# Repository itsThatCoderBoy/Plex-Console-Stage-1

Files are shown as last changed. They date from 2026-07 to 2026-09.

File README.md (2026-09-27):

# Plex Console Stage 1
## A small devboard that attaches to modules to give endless emulation possibilities!
The way it works is simple: Have the main board, attach it to whatever output device is needed for the game you want to play, and bam! You have a small pocket-sized devboard with endless possibilities of emulation. All you have to do is make your attachment board, code the game, and snap on the main board!\
**This is Stage 1 of this project; it is just the Devboard. After I build this project and it (hopefully) works, I am going to add a case and move on making a tester module.**\
This is my first project as part of Hack Club, and I certainly hope it isn't my last! This has already been so fun, even just a couple hours in.

## Why & How
This project came about because i really liked Bitluni's Megaplex video (oh boy I wonder where the name came from), and I wanted to make something inspired by it.\
I initially was thinking of doing something exactly like his, but then realised that that would be a bad idea, and so I decided to make it my own by adding:
 - Different battery (rechargable!)
 - Modular snap-on system
 - Completely different display (ok this is an entirely different thing)

Thank you so much to Hack Club and Forge for making this whole thing possible! This really is an amazing oppurtunity.

## What is it?
This project firstly involves a devboard. The reason it isn't a single board with the I/O and everything is because the main devboard is one of the more expensive things (~$35-40 including shipping for components), and I wanted you to just have one for all of the possible modules. (Also because I wanted a concrete starting point)\
**Note: This is a test for just the devboard. I am going to make a case and print it myself when I have confirmation that it works and I will be able to measure something concrete. Also, the 3D model on KiCad is missing quite a few componenets and I am going to need those in order to make a good case.**\
The second part of the project is the modules. They snap onto the devboard with magnets and communicate with pads on the back of both. Modules can do anything, as long as you code it right and have enough I/O pins!

## What's the Plan?
I currently have the devboard designed and ready to ship off to JLCPCB when I get funding!\
The first module that I am going to create is just a simple screen made of Charlie-Plexed LEDS. This is mainly just to practice coding, get the connection between the devboard and module hammered down, and make sure that the devboard works of course.\
After that, I move on to the main idea: The Nintendon't GameMan. This is basically a Gameboy-like little pocket console with famous games like Tesris, Pac-Boy, and maybe even Toader! I haven't gotten to this point yet of course, but I am moving swiftly along.
Last but not least, if I have any extra time, I'd eventually like to make other attachments (feel free to leave suggestions).

## Current Progress:

### *Devboard*
*Schematic*\
Schematic of Devboard

*PCB Layout*\
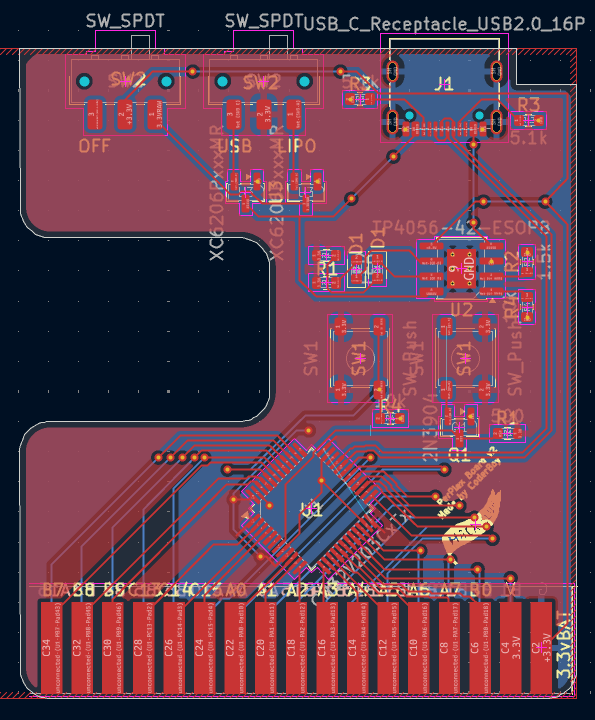
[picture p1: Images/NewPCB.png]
PCB Layout of Devboard


*Built-in KiCad 3D Model Front*\
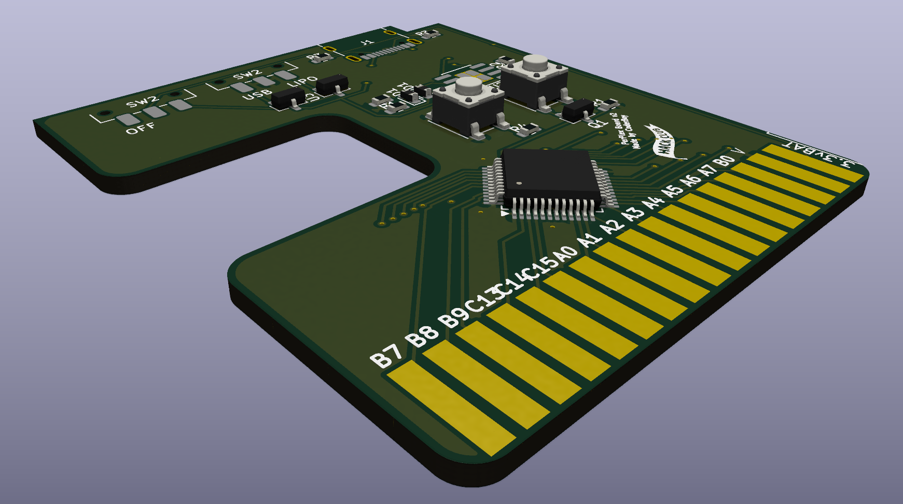
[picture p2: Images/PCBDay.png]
Built-in KiCad 3D Model Front of Devboard


*Build Photo*
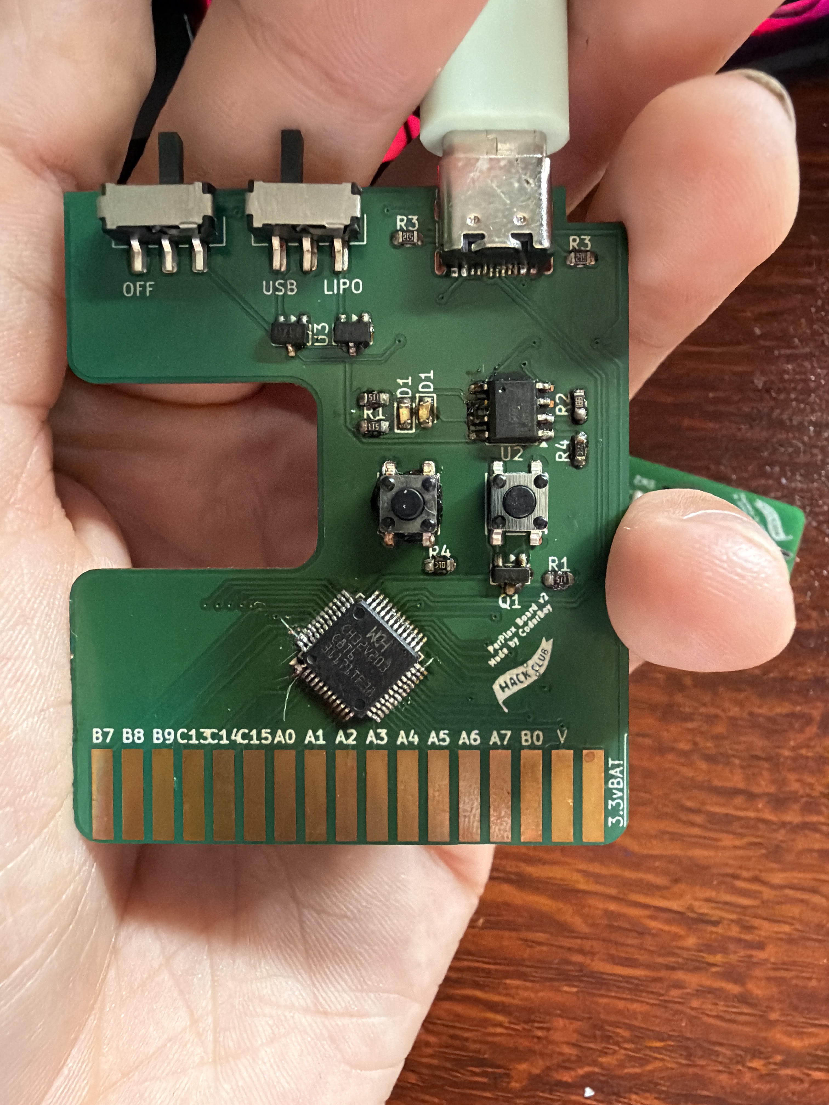
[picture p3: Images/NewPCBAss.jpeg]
Build Photo


## BOM

DevboardBOM

## Build

[View my project timeline on Lapse](https://lapse.hackclub.com/user/@itsthatcoderboy)

https://github.com/user-attachments/assets/fe2d55e1-1f7b-49ab-ab0b-663dc05e2e7f

https://github.com/user-attachments/assets/89aea018-e0ea-4a9d-9f60-57c4afef2afe

https://github.com/user-attachments/assets/4f556e5a-54bf-4c0b-9238-5e6fd982241c

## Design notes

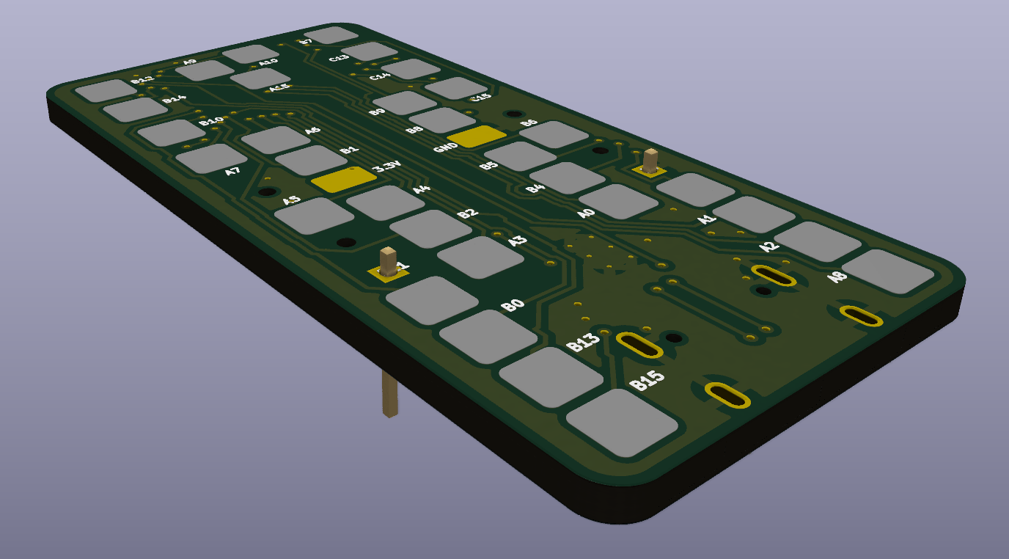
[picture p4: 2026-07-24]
Images/PCBBack.png

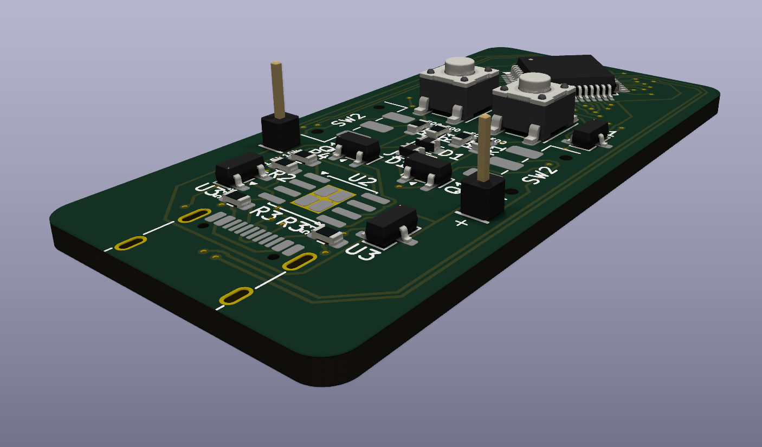
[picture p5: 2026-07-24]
Images/PCBFront.png

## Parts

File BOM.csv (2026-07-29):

Devboard BOM
Components: |  |  |  |  |  | Just For Me
Reference | Value | Qty | Footprint | Shop Link: | Shop Details: | Will I need to buy it? | Shipping? (^ = ships with) | Coupon?
D1 | LED (Any Color) | 2 | D_0603 (1608 Metric) | lcsc.com/product-detail/C19273151.html | LCSC - $ 0.59 for 100 | Y | $12.57 (includes Handling fee) | N
J1 | USB-C 2.0 16pin Jack | 1 | USB-C Receptacle G-Switch GT-USB-7010ASV | lcsc.com/product-detail/C5178539.html | LCSC - $ 0.36 for 5 | Y | ^ | N
Q1 | 2N3904 Transistor | 3 | SOT-23 | lcsc.com/product-detail/C18536.html | LCSC - $ 0.29 for 25 | N
R1 | 500Ω | 5 | R_0603 (1608 Metric) | lcsc.com/product-detail/C6207671.html | LCSC - $ 0.63 for 20 | N
R2 | 1.5kΩ | 1 | R_0603 (1608 Metric) | lcsc.com/product-detail/C2930050.html | LCSC - $ 0.29 for 100 | N
R3 | 5.1kΩ | 2 | R_0603 (1608 Metric) | lcsc.com/product-detail/C2907044.html | LCSC - $ 0.28 for 100 | N
R4 | 10kΩ | 2 | R_0603 (1608 Metric) | lcsc.com/product-detail/C2906982.html | LCSC - $ 0.42 for 100 | N
SW1 | Push-Button Switch | 2 | SW SPST PTS647 Sx38 | lcsc.com/product-detail/C36938886.html | LCSC - $ 1.01 for 50 | Y | ^ | N
SW2 | SPDT Slide Switch | 2 | SW SPDT CK JS102011SAQN | lcsc.com/product-detail/C49023767.html | LCSC - $ 0.39 for 5 | Y | ^ | N
U1 | CH32V203C8T6 | 1 | LQFP-48 7x7mm P0.5mm | lcsc.com/product-detail/C3001172.html | LCSC - $ 0.87 for 1 | Y | ^ | N
U2 | TP4056-42-ESOP8 | 1 | SOIC-8-1EP 3.9x4.9mm P1.27mm EP2.41x3.3mm ThermalVias | lcsc.com/product-detail/C16581.html | LCSC - $ 0.93 for 5 | Y | ^ | N
U3 | XC6206P302MR-G | 1 | SOT-23 | lcsc.com/product-detail/C9972.html | LCSC - $ 0.81 for 5 | Y | ^ | N
BATTERY | 802045 800 mAh | 1 | 8 mm x 20 mm x 45 mm | ebay.com/itm/254702348768 | Ebay - $ 7.22 for 1 | Y | $2.99 | N
Items:
PCB |  | 1 |  | jlcpcb.com | JLCPCB - $5.10 for 5 | Y | $3.22 | Y, -$ 5
Solder Paste |  | 1 |  | aliexpress.us/item/3256809162577166.html | AliExpress - $ 4.37 for 10g | Y | Free | Y, -$ 3.38
Total (For Me): | $ 17 @ LCSC, $ 10.21 @ Ebay, $ 1.07 @ AliExpress, $ 3.22 @ JLCPCB = $ 31.50*
Total Raw: | $ 19.37 @ LCSC, $ 10.21 @ Ebay, $ 4.37 @ AliExpress, $ 8.22 @ JLCPCB = $ 39.88*
 | * Note: There may be taxes, so add a little bit to cover that

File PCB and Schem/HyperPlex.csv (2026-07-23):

'Reference' | 'Value' | 'Footprint' | 'Qty'
'D1,D2' | 'LED' | 'Diode_SMD:D_0603_1608Metric' | '2'
'J1' | 'USB_C_Receptacle_USB2.0_16P' | 'Connector_USB:USB_C_Receptacle_G-Switch_GT-USB-7010ASV' | '1'
'Q1,Q2,Q3' | '2N3904' | 'Package_TO_SOT_SMD:SOT-23' | '3'
'R1,R14' | '10k' | 'Resistor_SMD:R_0603_1608Metric' | '2'
'R2' | '1.5k' | 'Resistor_SMD:R_0603_1608Metric' | '1'
'R3,R4,R5,R6,R15' | '500' | 'Resistor_SMD:R_0603_1608Metric' | '5'
'R12,R13' | '5.1k' | 'Resistor_SMD:R_0603_1608Metric' | '2'
'SW1,SW4' | 'SW_Push' | 'Button_Switch_SMD:SW_SPST_PTS647_Sx38' | '2'
'SW2,SW3' | 'SW_SPDT' | 'Button_Switch_SMD:SW_SPDT_CK_JS102011SAQN' | '2'
'U1' | 'CH32V203CxTx' | 'Package_QFP:LQFP-48_7x7mm_P0.5mm' | '1'
'U3,U6' | 'XC6206PxxxMR' | 'Package_TO_SOT_SMD:SOT-23' | '2'
'U4' | 'TP4056-42-ESOP8' | 'Package_SO:SOIC-8-1EP_3.9x4.9mm_P1.27mm_EP2.41x3.3mm_ThermalVias' | '1'

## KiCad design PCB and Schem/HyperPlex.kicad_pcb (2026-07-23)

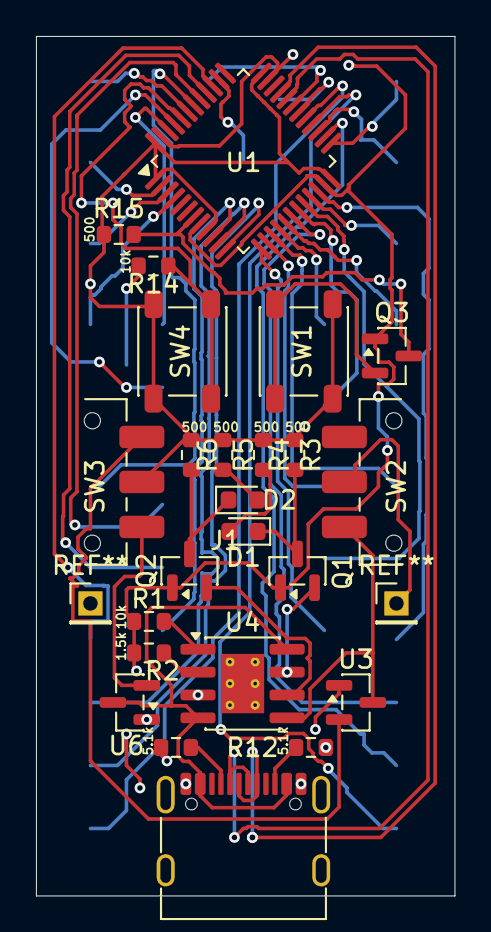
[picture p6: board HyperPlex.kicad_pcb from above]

Board: 2 copper layers, 23.2 x 47.8 mm, 25 parts (1 on the bottom side), 21 nets.

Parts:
D1, D2: LED; D_0603_1608Metric
HyperPlex: HyperPlex Connector
J1: USB_C_Receptacle_USB2.0_16P; USB_C_Receptacle_G-Switch_GT-USB-7010ASV
Q1, Q2, Q3: 2N3904; SOT-23
R1, R14: 10k; R_0603_1608Metric
R2: 1.5k; R_0603_1608Metric
R3, R4, R5, R6, R15: 500; R_0603_1608Metric
R12, R13: 5.1k; R_0603_1608Metric
SW1, SW4: SW_Push; SW_SPST_PTS647_Sx38
SW2, SW3: SW_SPDT; SW_SPDT_CK_JS102011SAQN
U1: CH32V203CxTx; LQFP-48_7x7mm_P0.5mm
U3, U6: XC6206PxxxMR; SOT-23
U4: TP4056-42-ESOP8; SOIC-8-1EP_3.9x4.9mm_P1.27mm_EP2.41x3.3mm_ThermalVias

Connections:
/3.3V: HyperPlex.3.3V, R3.1, R4.1, R5.1, R6.1, R15.1, SW1.2, SW3.2 (B), SW4.1, U1.1 (VBAT), U1.9 (VDDA), U1.24 (VDD_VIO), U1.36 (VDD), U1.48 (VDD)
/3.3VRAW: SW2.1 (A), U3.3 (VI), U4.5 (BAT)
/RST: Q3.3 (C), R15.2, U1.7 (~RST)
/USB5V: J1.A4 (VBUS), J1.A9 (VBUS), J1.B4 (VBUS), J1.B9 (VBUS), U4.4 (V_{CC}), U4.8 (CE), U6.3 (VI)
/USBDN: J1.A7 (D-), J1.B7 (D-), U1.32 (PA11)
/USBDP: J1.A6 (D+), J1.B6 (D+), U1.33 (PA12)
GND: HyperPlex.GND, J1.A1 (GND), J1.A12 (GND), J1.B1 (GND), J1.B12 (GND), J1.SH (SHIELD), Q1.1 (E), Q2.1 (E), Q3.1 (E), R1.2, R2.2, R12.2, R13.2, R14.1, U1.8 (VSSA), U1.23 (VSS), U1.35 (VSS), U1.47 (VSS), U3.1 (GND), U4.3 (GND), U4.9 (EPAD), U6.1 (GND)
unnamed: D1.2 (A), R4.2
unnamed: D1.1 (K), Q1.3 (C), R3.2
unnamed: D2.2 (A), R5.2
unnamed: D2.1 (K), Q2.3 (C), R6.2
unnamed: J1.A5 (CC1), R13.1
unnamed: J1.B5 (CC2), R12.1
unnamed: Q1.2 (B), U4.7 (~CHRG)
unnamed: Q2.2 (B), U4.6 (~STDBY)
unnamed: Q3.2 (B), SW1.1
unnamed: SW3.1 (A), U3.2 (VO)
unnamed: SW3.3 (C), U6.2 (VO)
unnamed: R14.2, SW4.2, U1.44 (BOOT0)
unnamed: R2.1, U4.2 (PROG)
unnamed: R1.1, U4.1 (TEMP)

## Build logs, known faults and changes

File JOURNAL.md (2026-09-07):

---
title: "HyperPlex Console"
author: "itsThatCoderBoy"
description: "A small devboard that attaches to modules to give endless emulation possibilities!"
created_at: "2026-03-20"
---

# July 21 - Created Journal, Did Research, Started Schematic

Through research, I've found that I can use the MounRiver Studio IDE for programming the chip I am going to be using, the CH32V203C8T6. I already picked out components I am going to be using.\
This has definitely been a lot more looking at datasheets than I expected lol. So far it's going very well, I have the Filter, Charger, and PSU for the charger designed in schematic.\
Currently working on the devboard that will attach to the console, the idea is basically a swap-out system where you can attach the devboard onto various modules, the first of which will be the game console.\
Bruh I just spent like 45 minutes on making a 5v power supply for the charger. The USB plug has to provide the power and it's already 5V :( Not a pro gamer move. Does mean there's one less thing to fit on the PCB!

**TO-DO (Schematic):**
 - LDO Filter :D
 - 5V Supply for Charger :D
 - Charger :D
 - Storage Unit
 - Pinout :D

**Total time spent: ~2.75 Hours**

Schematic

# July 22 - Finished Devboard Schematic, Finished Devboard PCB, Worked on README

I'm doing very well so far! I've decided to put the storage module on the attachment board, just so that you can only play games that are compatible with the module to prevent letting the magic smoke out.\
Made minor changes to schematic (mainly changing the charging rate resistor value)\
I want to put the LiPo battery on the board, but the only way I can do that and not extend the board dramatically is to put it on the bottom. There is space, but that would make it so that I'd have to add a connector to the attachment pads, and I don't know how I'm going to do that.\
It might be possible to do something like an extender?? I don't know.\
I can't figure out how to get a custom footprint to only appear on the bottom leyer. Time to Google! - Figured it out; I didn't have bottom footprints visible lol.\
I had an idea! What if I just kind of mount the lipo in top of the board? The only thing with that would be that the buttons would be blocked. Not sure.\
Devboard PCB layout finished! Going to get a quote from PCBWay/JLCPCB to see what that expense will be. Probably will see in the morning.

**TO-DO (Schematic):**
 - LDO Filter :D
 - 5V Supply for Charger :D
 - Charger :D
 - Storage Unit - Not adding
 - Pinout :D
 - Reset Button :D
 - USB Jack :D

**TO-DO (Devboard PCB):**
 - Organise Components :D
 - Make Footprint for Connector :D
 - Decide Where LiPo Goes - I think it will just be in the 3D-Printed case somewhere
 - Route Everything But Bottom Pads :D
 - Route Bottom Pads :D

Note: :D means that I did that task

**Total time spent: ~6 Hours**

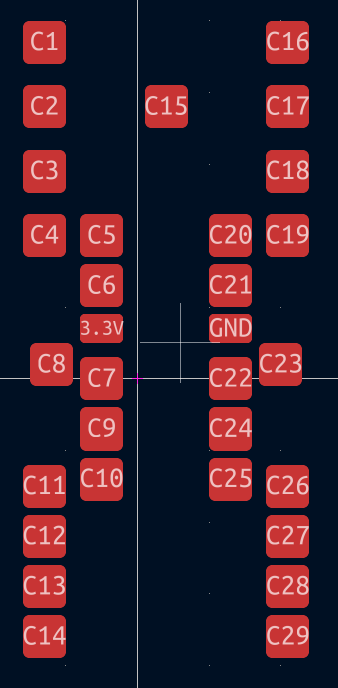
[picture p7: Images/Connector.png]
Connector

Schematic
PCB

# July 23 - BOM & Checking Everything on Devboard

Today was a much shorter day than yesterday, but I did get the BOM for the devboard done, which is very important.\
I've been mainly looking at various websites (LCSC, ALiExpress, JLCPCB, etc.) to see which can offer the best prices. I've mainly found that LCSC can offer really good prices for electronic components. I am getting the PCB from JLC because it was like 3 dollars cheaper.\
I will be sending my BOM to the Slack to see if I'm getting scammed, thoough, so hopefully I get good deals.\
I've also been working on checking everything on the devboard to see if there are any glaring issues, and so far I haven't seen any.\
After asking a couple questions, I've found that it would be a better idea to have each stage as its own project. This one, then, is about ready for a review, all I have to do is make a cover image!\
Another thing that I did today was some troubleshooting with figuring out what I will be able to code with. It seems like I can use Arduino IDE, but I've had quite a bit of trouble with installing the necessary packages. I think I am going to use CH32FUN, because I saw it recommended in a few places, and it seems mostly like Arduino IDE, as well as natively supporting my MCU I will be using. The main thing is that it mainly works by editing files in a text editor, and so I am going to need to find a way to be able to track it on Hackatime.

**Total time spent: ~3.3 Hours**

BOM

# July 24 - Finishing Touches to PCB

Not a lot today, mainly some finishing touches to PCB. I've seen a lot on Slack about "rounding thy corners", so I did that. I also added the name of the board and the hack club logo. After that, I regenerated the GRBRs and sent them to JLC.\
I am also going to update the readme fully with updated pictures of everything.

**Total time spent: ~0.3 Hours**

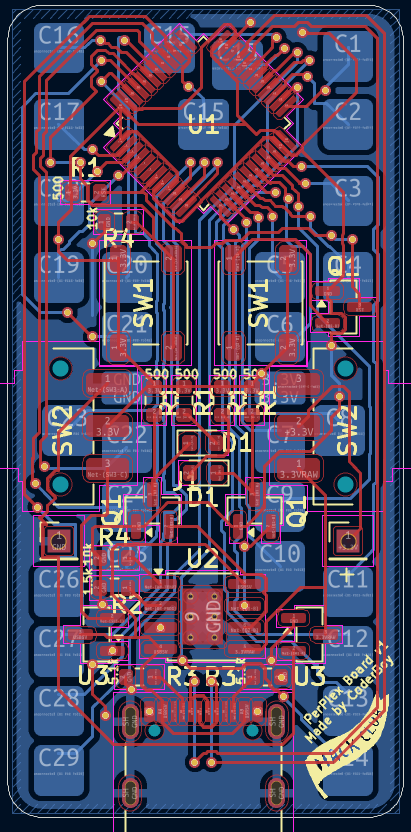
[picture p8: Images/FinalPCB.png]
Final PCB


# July 29 - Making Purchases!

I got approved!!!! I'm so excited :3\
I made my purchases on LCSC, AliExpress, and Ebay fine, but with JLC there were a few unexpected things like sales tax and the fact that my $5 coupon is too much and it can't be applied at checkout, making the total exceed the $3.22 left in my grant, and I ended up buying it myself. It was like $8 so it's fine.\
Overall, I am incredibly excited to work on building this project. I will be adding journal entries whenever something arrives.\
I have my workspace all set up!

**Total time spent: ~0.75 Hours**

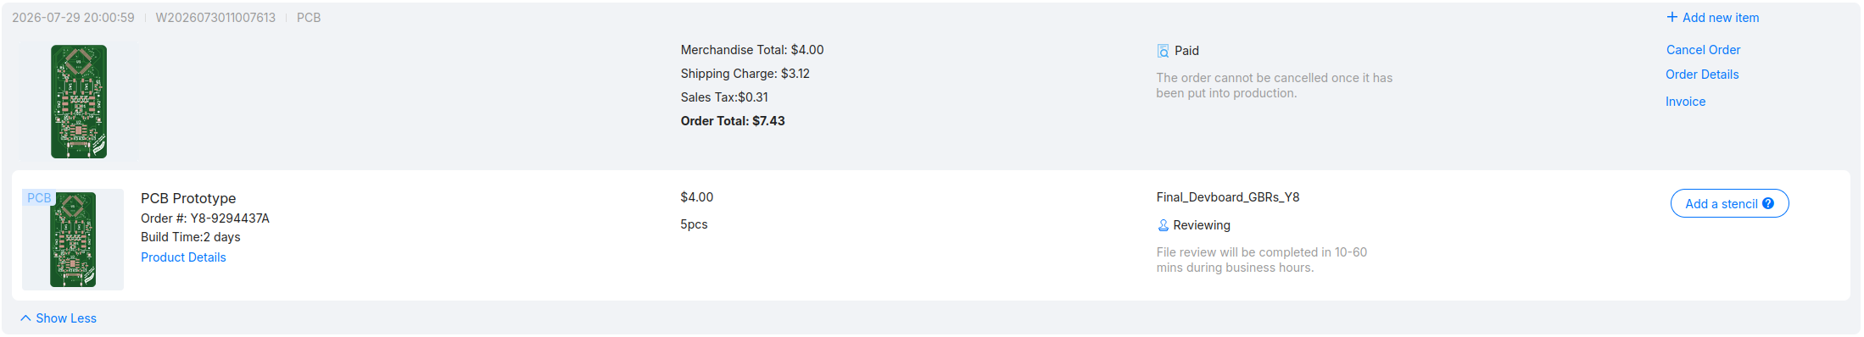
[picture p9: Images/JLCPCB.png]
JLCPCB


# August 1 - Modeling a Component Holder & Preparing Workspace

Not too much today, mainly just waiting for components. I did model a small component holder, which will hopefully help the soldering process go much quicker.\
I got an 0603 component kit, so that is why I am making the bins today. I will be putting the correct amount in each.

**Total time spent: ~0.5 Hours**

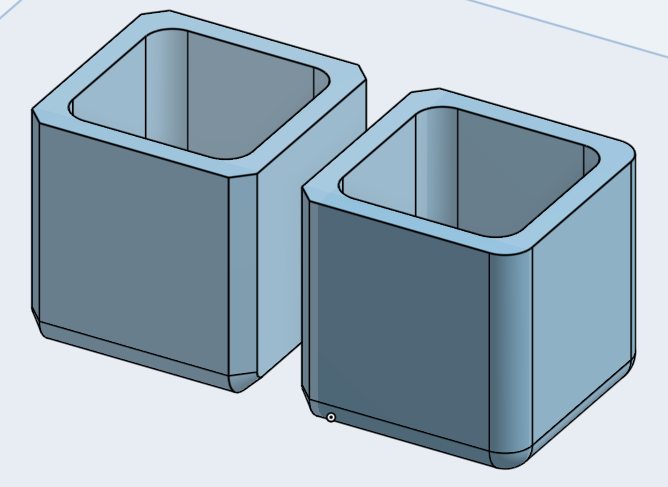
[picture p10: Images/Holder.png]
Holder


# August 9 - Working on Soldering!!!

Big day today!! The components came, and and I worked on soldering them to the boards which also came today!! It was pretty difficult, because this is the first time I've been working with such itty-bitty components, and I burned myself a couple times lol.\
However, I have come across a couple problems. First of all, tombstoning. I looked it up and I think I can fix it by heating the hotplate up with the PCB on it. Secondly, I ran into the problem where the PCB was getting cooked. This might be becuase it's too thick; the PCB is getting burnt before the top reaches melting temps.\
I also am annoyed that I didn't get any extra controllers; I bridged a couple of the pins and it's been a nightmare trying to get them to seperate. However, I did get a slightly working prototype - it charged the battery!!! The only problem is that I then made 2 mistakes: first, I put the board on the hotplate while the battery was still connected, and one of the ICs on the battery got really big. However, it still works. Then, after reflowing the usb jack, I made the mistake of not gripping it tightly enough, and it fell and most on the components got messed up. Hopefully I can fix this soon, I have 2 boards left.\

**Total time spent: ~2 Hours**

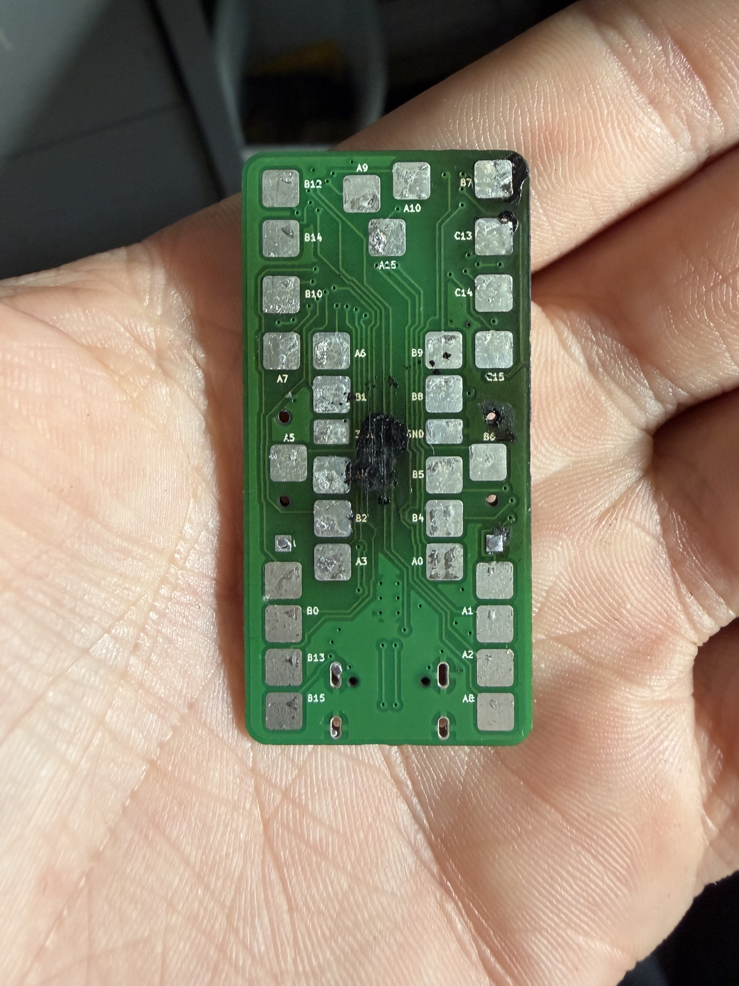
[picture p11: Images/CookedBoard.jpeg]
Cooked Board


# August 15 - Working on Soldering 2: Electric Boogaloo!

Boy oh boy! Today was a day, and it was exciting! First of all, the good news: I got a second prototype; the only problem is that I'm not going to attach the controller because some pins are bridged. The prototype does charge the battery, but neither of the lights work. I really should've added labels to the power switches.\
I've noticed some flaws, mostly the pads on the back; I just don't think that they're practical, I should switch to fingers. I think I'm going to design new PCBS.\

**Total time spent: ~1.5 Hours**

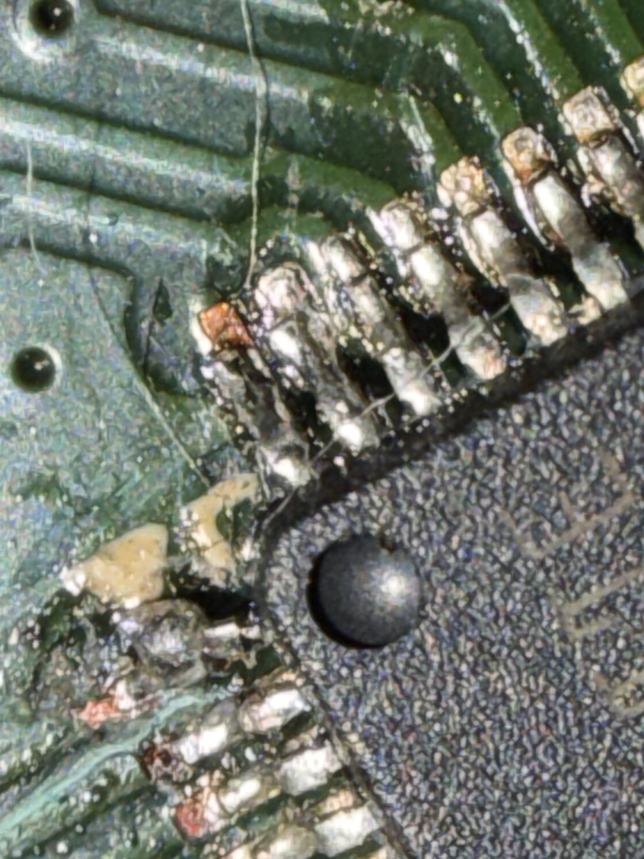
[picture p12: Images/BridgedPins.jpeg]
Bridged Pins


# August 23 - Designing New PCBS: The Old Ones are Bad™

I designed new PCBS! They are designed to fit inside of a model Gameboy Cartridge I made, and so hopefully it'll look cool!\
On a more serious note, I've changed a lot - they're going to be thinner, they're larger, they have fingers instead of bottom pads, and the components are a lot more spread out to hopefully make assembly easier.\
I also ordered some replacement controllers from AliExpress. They should be here soon!\

**Total time spent: ~2.25 Hours**

New Design!

# September 6 - Soldering Again!

The new PCBS got here! I was more experienced this timne around, so it wasn't too bad, just a couple minor burns lol\
I didn't cook a single one! The most difficult part was the controller, and I had to spend an unreasonable amount of time to assure that the pins weren't bridged. It did end up working out, and I'm going to try to flash a blink program tomorrow.\
i made the decision to remove th not gates on the LEDS, and they do light up!\

**Total time spent: ~1.5 Hours**

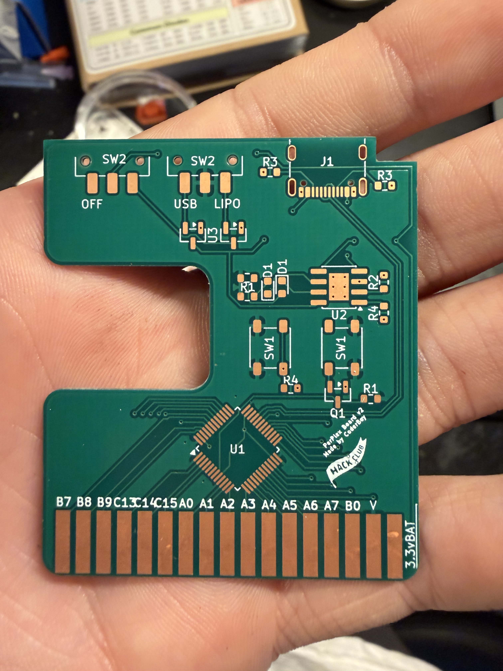
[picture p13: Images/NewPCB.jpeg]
New PCB!

New PCB Assembled!!

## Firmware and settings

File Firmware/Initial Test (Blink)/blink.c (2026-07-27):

// Thank you to cnlohr for making ch32fun!!!

#include "ch32fun.h"
#include <stdio.h>

// Name GPIO Pins
#define PIN_1 PA0

int main()
{
	SystemInit(); // Init System

	funGpioInitAll(); // Enable GPIOs
	
	funPinMode(PIN_1, GPIO_Speed_10MHz | GPIO_CNF_OUT_PP); // Set PIN_1 to output

	while(1)
	{
		funDigitalWrite(PIN_1, FUN_HIGH); // Turn on PIN_1
		Delay_Ms(250);
		funDigitalWrite(PIN_1, FUN_LOW);  // Turn off PIN_1
		Delay_Ms(250);
	}
}

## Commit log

2026-07-22 Added journal and began Schematic
    [HyperPlex.kicad_pcb, HyperPlex.kicad_sch]
2026-07-22 Added USB Jack, Power switch, and Reset button to schematic
    [HyperPlex.kicad_sch]
2026-07-22 Updated journal to reflect wasted time on 3.3-5V converter, started work on additional memory schematic
    [HyperPlex.kicad_sch]
2026-07-22 Added journal entry 2, finished schematic, began PCB layout
    [HyperPlex.kicad_sch]
2026-07-23 Elaborated on journal, tentatively finished devboard PCB
    [HyperPlex-B_Cu.gbr, HyperPlex-B_Mask.gbr, HyperPlex-B_Paste.gbr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]
2026-07-23 Updated Journal and README
    [HyperPlex.csv, HyperPlex.kicad_pcb]
2026-07-24 Updated BOM
2026-07-24 Rounded edges of PCB and regenerated GRBRs
    [HyperPlex-B_Cu.gbr, HyperPlex-B_Mask.gbr, HyperPlex-B_Paste.gbr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]
2026-07-24 Added Hack Club logo and name to PCB
    [HyperPlex-B_Cu.gbr, HyperPlex-B_Mask.gbr, HyperPlex-B_Paste.gbr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]
2026-07-29 Moved BOM to root
    [BOM.csv]
2026-09-07 Updated journals, added photos
    [HyperPlex-B_Cu.gbr, HyperPlex-B_Mask.gbr, HyperPlex-B_Paste.gbr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]
